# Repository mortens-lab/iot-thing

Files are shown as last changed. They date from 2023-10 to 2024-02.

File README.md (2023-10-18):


# iot-thing
Universal iot device based on an ESP32 WROOM module

KiCad 7.0 files for device

<a href="https://www.pcbway.com/project/shareproject/iot_thing_universal_iot_development_board_fe54c4ad.html">PCB from PCBWay</a>

IMAGE ALT TEXT (http://www.youtube.com/watch?v=b-7bMl6fJio "Video Title")

Link to YouTube video : (https://youtu.be/b-7bMl6fJio)

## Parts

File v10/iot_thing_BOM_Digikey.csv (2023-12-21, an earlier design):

Reference | Value | Footprint | Digikey | Qty
C1, C3, C7, C9, C10, C13, C14 | 100n | Capacitor_SMD:C_0402_1005Metric_Pad0.74x0.62mm_HandSolder | 490-10700-1-ND | 7
C2, C4, C6, C8, C11, C12 | 22u | Capacitor_SMD:C_0805_2012Metric | 1276-2910-1-ND | 6
C5 | 4u7 | Capacitor_SMD:C_0805_2012Metric | 1276-6464-1-ND | 1
C15 | 1000u/25V | Capacitor_THT:CP_Radial_D10.0mm_P5.00mm | 732-8835-1-ND | 1
C16 | 4u7 | Capacitor_SMD:C_0805_2012Metric_Pad1.18x1.45mm_HandSolder | 1276-6464-1-ND | 1
D1 | LED_RGBA | LED_SMD:LED_RGB_Wuerth-PLCC4_3.2x2.8mm_150141M173100 | 732-4998-1-ND | 1
D2 | LL4148 | Diode_SMD:D_MiniMELF | 4878-LL4148CT-ND | 1
D3 | YELLOW | LED_SMD:LED_0603_1608Metric | 732-4981-1-ND | 1
D4 | GREEN | LED_SMD:LED_0603_1608Metric | 732-4980-1-ND | 1
F1 | Polyfuse 1A | Fuse:Fuse_1206_3216Metric | F3371CT-ND | 1
F3 | Fuse | 00_morten_Library:FUSE_696105003002 | 732-11373-ND | 1
FB1 | BLM21PG221 | Inductor_SMD:L_0805_2012Metric_Pad1.05x1.20mm_HandSolder | 490-1054-1-ND | 1
H1-H4 | Hole_Pad | MountingHole:MountingHole_3.2mm_M3_Pad_Via | N/A | 4
J1 | Conn_01x04 | Connector_JST:JST_SH_SM04B-SRSS-TB_1x04-1MP_P1.00mm_Horizontal | 455-SM04B-SRSS-TBCT-ND | 1
J2 | USB_C_Receptacle_USB2.0 | Connector_USB:USB_C_Receptacle_HRO_TYPE-C-31-M-12 | LCSC : Korean Hroparts Elec TYPE-C-31-M-12 | 1
J3 | Screw_Terminal_01x03 | TerminalBlock_Phoenix:TerminalBlock_Phoenix_MKDS-3-3-5.08_1x03_P5.08mm_Horizontal | 732-10996-ND | 1
J4 | Screw_Terminal_01x02 | TerminalBlock_Phoenix:TerminalBlock_Phoenix_MKDS-1,5-2-5.08_1x02_P5.08mm_Horizontal | 732-691253510002-ND | 1
J5 | Screw_Terminal_01x08 | TerminalBlock_Phoenix:TerminalBlock_Phoenix_MKDS-1,5-8-5.08_1x08_P5.08mm_Horizontal | 732-691244510008-ND | 1
J6 | Conn_02x05_Odd_Even | Connector_PinHeader_2.54mm:PinHeader_2x05_P2.54mm_Vertical | Standard Pins 2x5 0.254 | 1
K1 | RT314A05 | Relay_THT:Relay_SPDT_Schrack-RT1-16A-FormC_RM5mm | PB1695-ND | 1
Q2 | UMH3N | Package_TO_SOT_SMD:SOT-363_SC-70-6 | UMH3NFHATNCT-ND | 1
Q3 | BC817 | Package_TO_SOT_SMD:SOT-23 | BC817-40-TPMSCT-ND | 1
R1, R6, R12, R14 | 10K | Resistor_SMD:R_0402_1005Metric_Pad0.72x0.64mm_HandSolder | 311-10.0KLRCT-ND | 4
R2, R3 | 5K1 | Resistor_SMD:R_0402_1005Metric_Pad0.72x0.64mm_HandSolder | 311-5.10KLRCT-ND | 2
R4, R5 | 4K7 | Resistor_SMD:R_0402_1005Metric_Pad0.72x0.64mm_HandSolder | 311-4.7KLRCT-ND | 2
R7, R8 | 22R | Resistor_SMD:R_0402_1005Metric_Pad0.72x0.64mm_HandSolder | 311-22.0LRCT-ND | 2
R9-R11, R13, R15, R16 | 1K | Resistor_SMD:R_0402_1005Metric_Pad0.72x0.64mm_HandSolder | 311-1.00KLRCT-ND | 6
R17-R20 | 47R | Resistor_SMD:R_0402_1005Metric_Pad0.72x0.64mm_HandSolder | 311-47.0LRCT-ND | 4
SW1 | SW_SPST | Button_Switch_SMD:SW_Push_1P1T_NO_6x6mm_H9.5mm | 679-2380-1-ND | 1
U1 | ESP32-WROOM-32D | RF_Module:ESP32-WROOM-32D | 1965-ESP32-WROOM-32E-N4CT-ND | 1
U2 | USBLC6-2P6 | Package_TO_SOT_SMD:SOT-666 | 497-5026-1-ND | 1
U3 | Si7021-A20 | Package_DFN_QFN:DFN-6-1EP_3x3mm_P1mm_EP1.5x2.4mm | 336-4380-1-ND | 1
U4 | CP2104 | Package_DFN_QFN:QFN-24-1EP_4x4mm_P0.5mm_EP2.6x2.6mm | 336-4146-1-ND | 1
U5 | TLV1117LV-33 | Package_TO_SOT_SMD:SOT-223-3_TabPin2 | 296-28778-1-ND | 1
U6 | 74AHCT245 | Package_DIP:DIP-20_W7.62mm | 296-1476-5-ND | 1

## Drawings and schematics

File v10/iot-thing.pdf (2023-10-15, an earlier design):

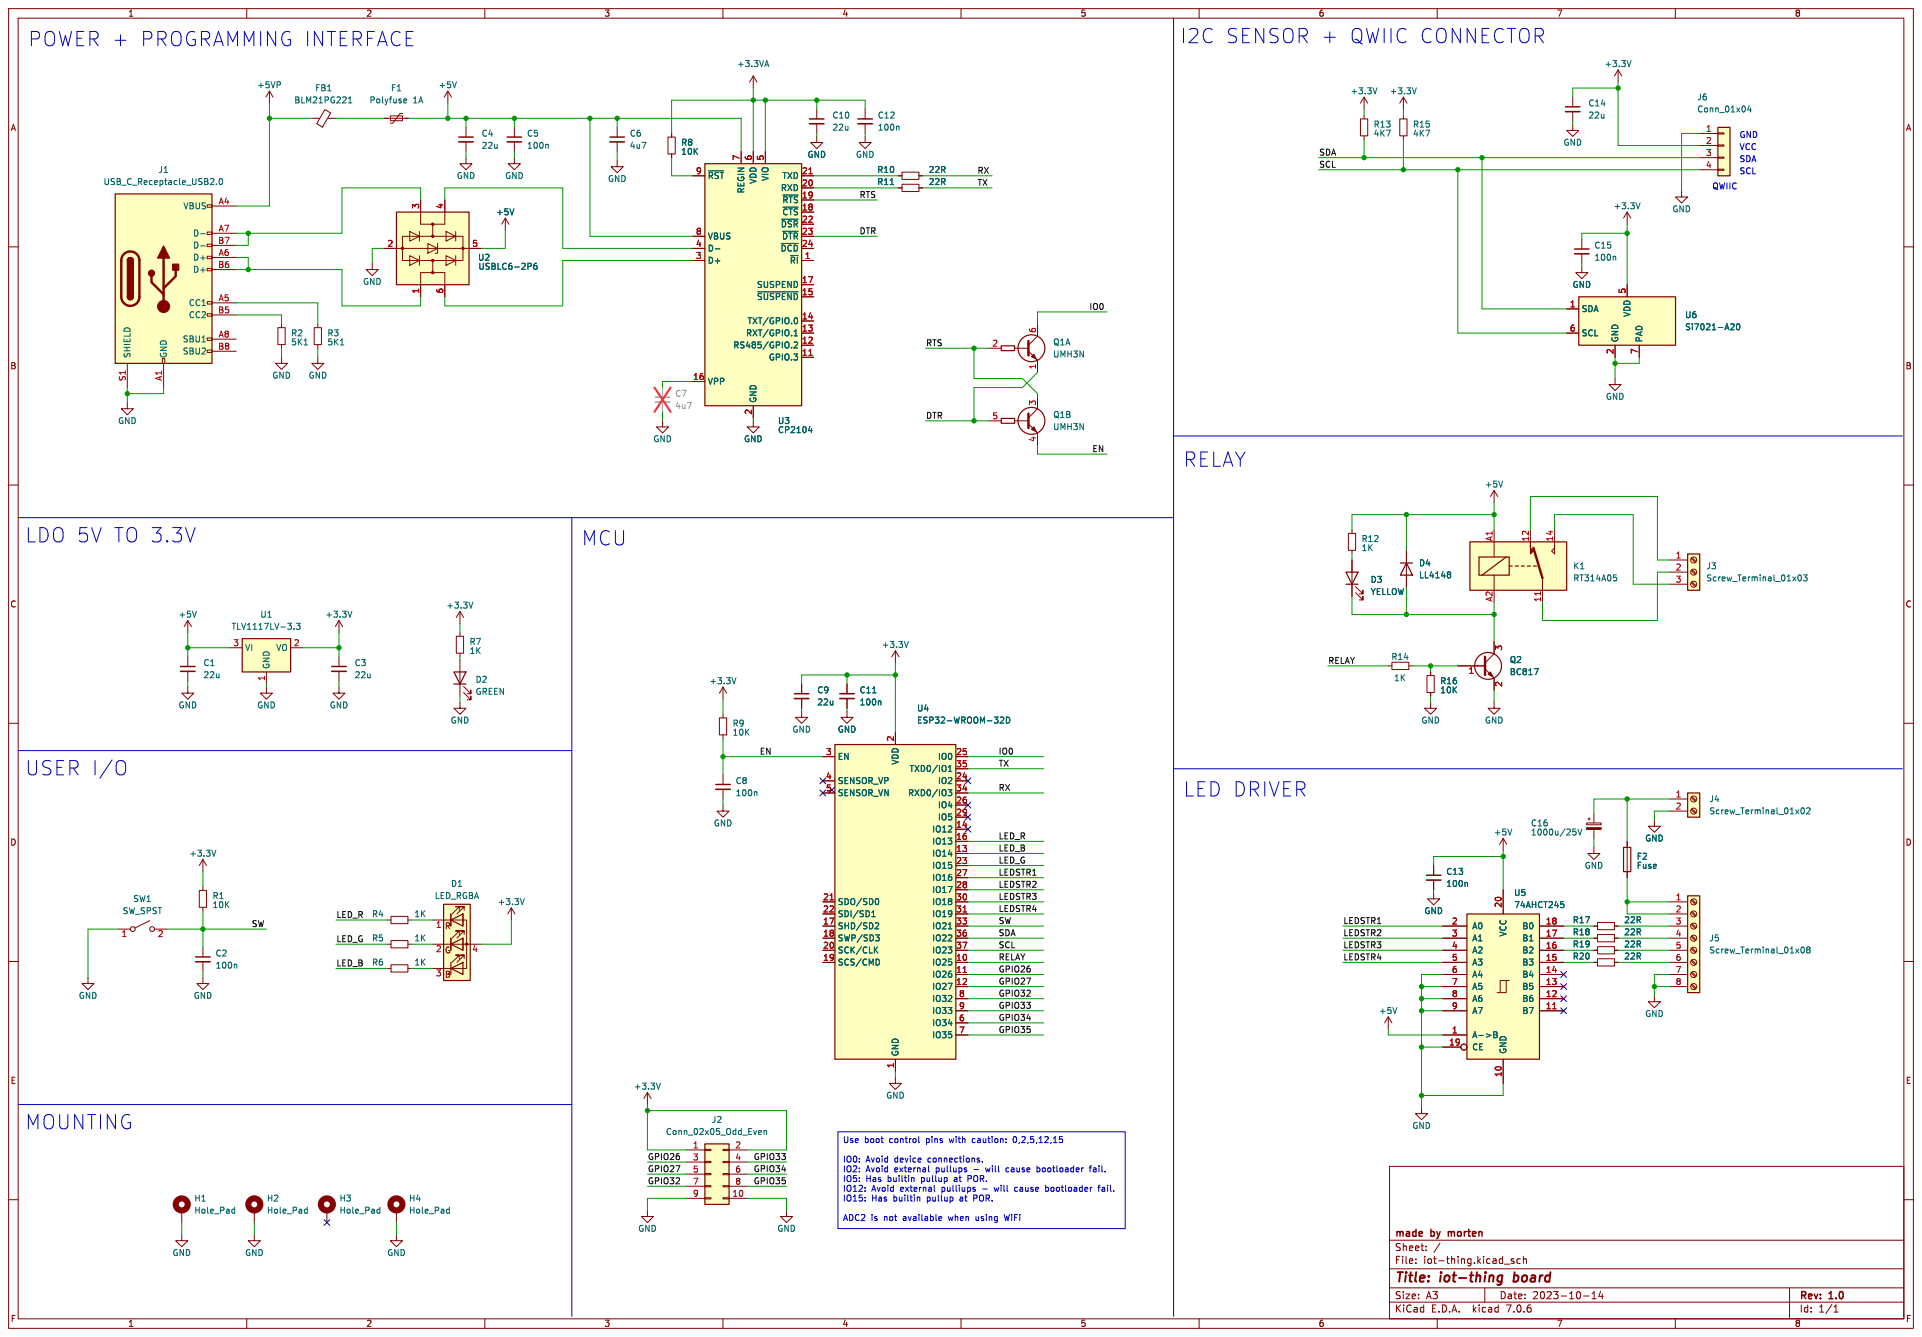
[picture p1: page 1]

2 RXD 20 TXD 21 ~{DSR} 22 ~{DTR} 23 ~{DCD} 24 D+ 3 D- 4 VIO

7 U6Si7021-A20 GND GND GND GND A1 VBUS A4 CC1 A5 D+ A6 D- A7 SBU1 A8 CC2 B5 D+ B6 D- B7 SBU2 B8 SHIELD S1

2 SCK/CLK 20 SDO/SD0 21 SDI/SD1 22

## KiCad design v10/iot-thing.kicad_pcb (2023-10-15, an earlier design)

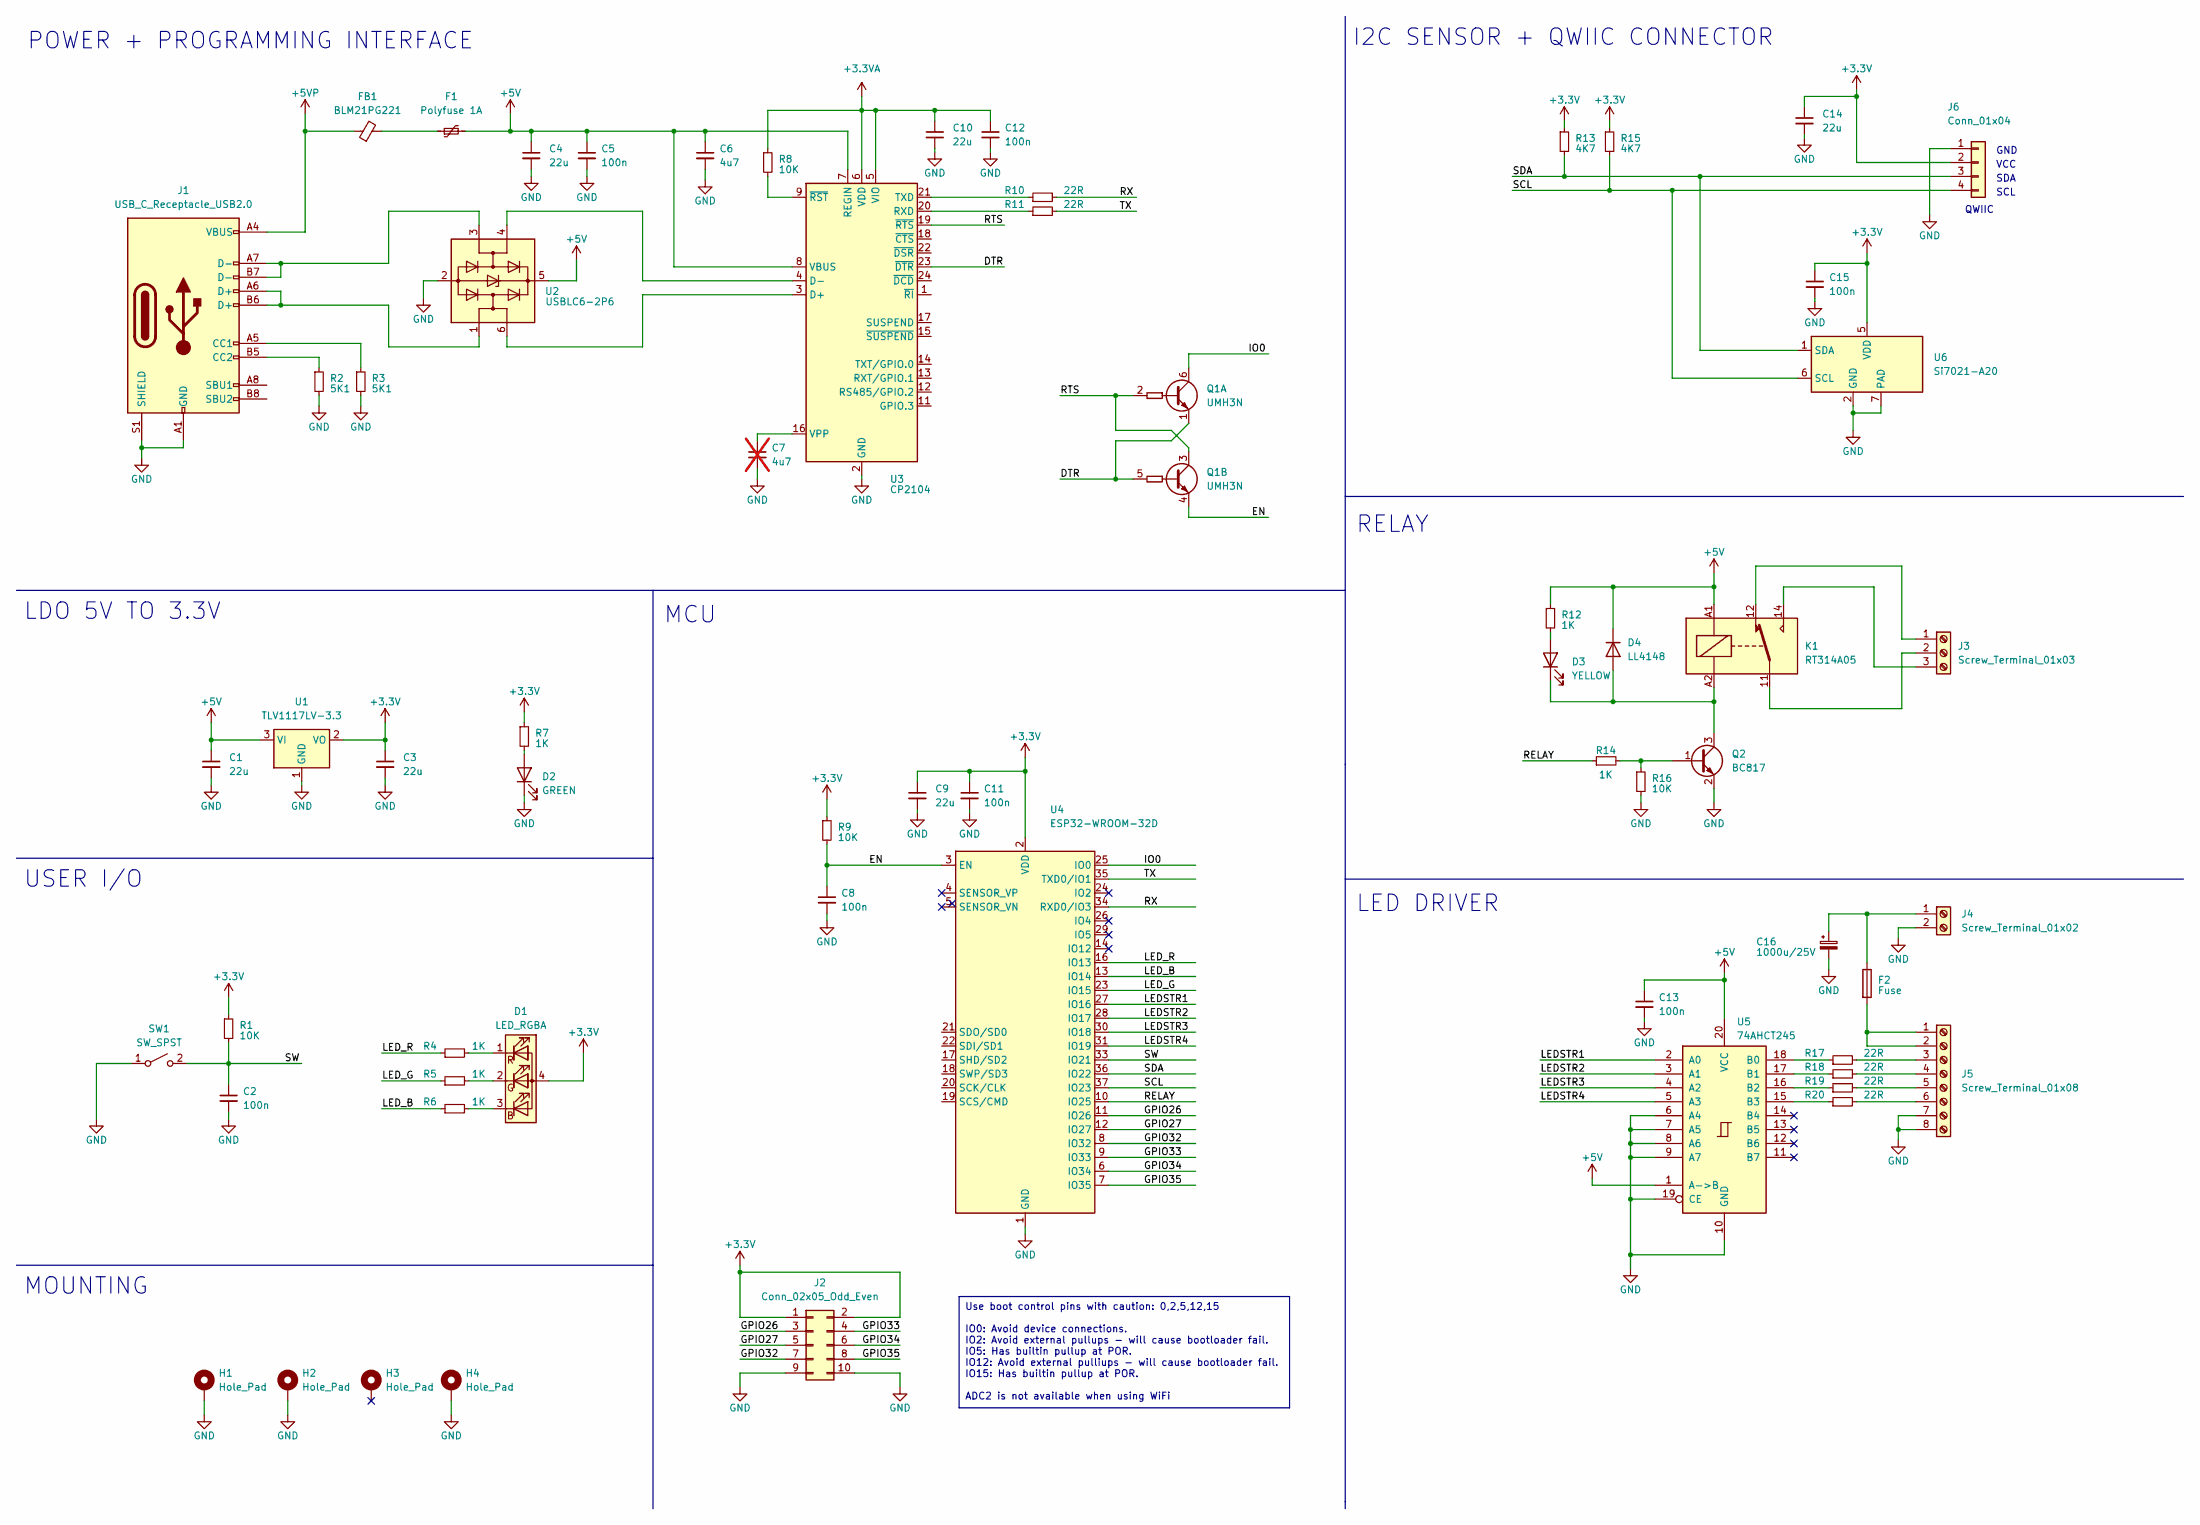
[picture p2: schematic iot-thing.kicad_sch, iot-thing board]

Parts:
C1, C3, C4, C9, C10, C14: 22u; C_0805_2012Metric_Pad1.18x1.45mm_HandSolder
C2, C5, C8, C11, C12, C13, C15: 100n; C_0402_1005Metric_Pad0.74x0.62mm_HandSolder
C6: 4u7; C_0805_2012Metric_Pad1.18x1.45mm_HandSolder
C7: 4u7; C_0805_2012Metric_Pad1.18x1.45mm_HandSolder; not fitted
C16: 1000u/25V; CP_Radial_D10.0mm_P5.00mm
D1: LED_RGBA; LED_RGB_Wuerth-PLCC4_3.2x2.8mm_150141M173100
D2: GREEN; LED_0603_1608Metric_Pad1.05x0.95mm_HandSolder
D3: YELLOW; LED_0603_1608Metric_Pad1.05x0.95mm_HandSolder
D4: LL4148; D_MiniMELF
F1: Polyfuse 1A; Fuse_1206_3216Metric_Pad1.42x1.75mm_HandSolder
F2: Fuse; FUSE_696105003002
FB1: BLM21PG221; L_0603_1608Metric_Pad1.05x0.95mm_HandSolder
H1, H2, H4: Hole_Pad; MountingHole_3.2mm_M3_Pad_Via
H3: Hole_Pad; MountingHole_3.2mm_M3_DIN965
J1: USB_C_Receptacle_USB2.0; USB_C_Receptacle_HRO_TYPE-C-31-M-12
J2: Conn_02x05_Odd_Even; PinHeader_2x05_P2.54mm_Vertical
J3: Screw_Terminal_01x03; TerminalBlock_Phoenix_MKDS-3-3-5.08_1x03_P5.08mm_Horizontal
J4: Screw_Terminal_01x02; TerminalBlock_Phoenix_MKDS-1,5-2-5.08_1x02_P5.08mm_Horizont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
J5: Screw_Terminal_01x08; TerminalBlock_Phoenix_MKDS-1,5-8_1x08_P5.00mm_Horizontal
J6: Conn_01x04; JST_SH_SM04B-SRSS-TB_1x04-1MP_P1.00mm_Horizontal
K1: RT314A05; Relay_SPDT_Schrack-RT1-16A-FormC_RM5mm
Q1: UMH3N; SOT-363_SC-70-6
Q2: BC817; SOT-23
R1, R8, R9, R16: 10K; R_0402_1005Metric_Pad0.72x0.64mm_HandSolder
R2, R3: 5K1; R_0402_1005Metric_Pad0.72x0.64mm_HandSolder
R4, R5, R6, R7, R12, R14: 1K; R_0402_1005Metric_Pad0.72x0.64mm_HandSolder
R10, R11, R17, R18, R19, R20: 22R; R_0402_1005Metric_Pad0.72x0.64mm_HandSolder
R13, R15: 4K7; R_0402_1005Metric_Pad0.72x0.64mm_HandSolder
SW1: SW_SPST; SW_Push_1P1T_NO_6x6mm_H9.5mm
U1: TLV1117LV-3.3; SOT-223-3_TabPin2
U2: USBLC6-2P6; SOT-666
U3: CP2104; QFN-24-1EP_4x4mm_P0.5mm_EP2.6x2.6mm
U4: ESP32-WROOM-32D
U5: 74AHCT245; DIP-20_W7.62mm
U6: Si7021-A20; DFN-6-1EP_3x3mm_P1mm_EP1.5x2.4mm

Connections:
+3.3V: C3.1, C9.1, C11.1, C14.1, C15.1, D1.4 (A), J2.1, J2.2, J6.2, R1.1, R7.1, R9.1, R13.1, R15.1, U1.2 (VO), U4.2 (VDD), U6.5 (VDD)
+3.3VA: C10.1, C12.1, R8.1, U3.5 (VIO), U3.6 (VDD)
+5V: C1.1, C4.1, C5.1, C6.1, C13.1, D4.1 (K), F1.2, K1.A1, R12.1, U1.3 (VI), U2.5 (VBUS), U3.7 (REGIN), U3.8 (VBUS), U5.1 (A->B), U5.20 (VCC)
+5VP: FB1.1, J1.A4 (VBUS), J1.A9 (VBUS), J1.B4 (VBUS), J1.B9 (VBUS)
/DTR: Q1.1 (E1), Q1.5 (B2), U3.23 (~DTR)
/EN: C8.1, Q1.4 (E2), R9.2, U4.3 (EN)
/GPIO26: J2.3, U4.11 (IO26)
/GPIO27: J2.5, U4.12 (IO27)
/GPIO32: J2.7, U4.8 (IO32)
/GPIO33: J2.4, U4.9 (IO33)
/GPIO34: J2.6, U4.6 (IO34)
/GPIO35: J2.8, U4.7 (IO35)
/IO0: Q1.6 (C1), U4.25 (IO0)
/LEDSTR1: U4.27 (IO16), U5.2 (A0)
/LEDSTR2: U4.28 (IO17), U5.3 (A1)
/LEDSTR3: U4.30 (IO18), U5.4 (A2)
/LEDSTR4: U4.31 (IO19), U5.5 (A3)
/LED_B: R6.1, U4.13 (IO14)
/LED_G: R5.1, U4.23 (IO15)
/LED_R: R4.1, U4.16 (IO13)
/RELAY: R14.1, U4.10 (IO25)
/RTS: Q1.2 (B1), Q1.3 (C2), U3.19 (~RTS)
/RX: R10.2, U4.34 (RXD0/IO3)
/SCL: J6.4, R15.2, U4.37 (IO23), U6.6 (SCL)
/SDA: J6.3, R13.2, U4.36 (IO22), U6.1 (SDA)
/SW: C2.1, R1.2, SW1.2 (B), U4.33 (IO21)
/TX: R11.2, U4.35 (TXD0/IO1)
GND: C1.2, C2.2, C3.2, C4.2, C5.2, C6.2, C7.2, C8.2, C9.2, C10.2, C11.2, C12.2, C13.2, C14.2, C15.2, C16.2, D2.1 (K), H1.1, H2.1, H4.1, J1.A1 (GND), J1.A12 (GND), J1.B1 (GND), J1.B12 (GND), J1.S1 (SHIELD), J2.9, J2.10, J4.2, J5.7, J5.8, J6.1, Q2.2 (E), R2.2, R3.2, R16.2, SW1.1 (A), U1.1 (GND), U2.2 (GND), U3.2 (GND), U3.25 (GND), U4.1 (GND), U4.15 (GND), U4.38 (GND), U4.39 (GND), U5.6 (A4), U5.7 (A5), U5.8 (A6), U5.9 (A7), U5.10 (GND), U5.19 (CE), U6.2 (GND), U6.7 (PAD)
unnamed: D1.3 (BK), R6.2
unnamed: D1.2 (GK), R5.2
unnamed: D1.1 (RK), R4.2
unnamed: D2.2 (A), R7.2
unnamed: D3.2 (A), R12.2
unnamed: D3.1 (K), D4.2 (A), K1.A2, Q2.3 (C)
unnamed: F1.1, FB1.2
unnamed: J1.A5 (CC1), R3.1
unnamed: J1.B5 (CC2), R2.1
unnamed: J1.A6 (D+), J1.B6 (D+), U2.1 (I/O1)
unnamed: J1.A7 (D-), J1.B7 (D-), U2.3 (I/O2)
unnamed: J3.1, K1.12
unnamed: J3.2, K1.11
unnamed: J3.3, K1.14
unnamed: C16.1, F2.1, J4.1
unnamed: F2.2, J5.1, J5.2
unnamed: J5.3, R17.2
unnamed: J5.4, R18.2
unnamed: J5.5, R19.2
unnamed: J5.6, R20.2
unnamed: Q2.1 (B), R14.2, R16.1
unnamed: U2.6 (I/O1), U3.3 (D+)
unnamed: U2.4 (I/O2), U3.4 (D-)
unnamed: R11.1, U3.20 (RXD)
unnamed: R10.1, U3.21 (TXD)
unnamed: C7.1, U3.16 (VPP)
unnamed: R8.2, U3.9 (~RST)
unnamed: R17.1, U5.18 (B0)
unnamed: R18.1, U5.17 (B1)
unnamed: R19.1, U5.16 (B2)
unnamed: R20.1, U5.15 (B3)

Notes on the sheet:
Use boot control pins with caution: 0,2,5,12,15 IO0: Avoid device connections. IO2: Avoid external pullups - will cause bootloader fail. IO5: Has builtin pullup at POR. IO12: Avoid external pulliups - will cause bootloader fail. IO15: Has builtin pullup at POR. ADC2 is not available when using WiFi
LDO 5V TO 3.3V
MOUNTING
GND
SCL
SDA
I2C SENSOR + QWIIC CONNECTOR
USER I/O
RELAY
MCU
QWIIC
LED DRIVER
POWER + PROGRAMMING INTERFACE
VCC

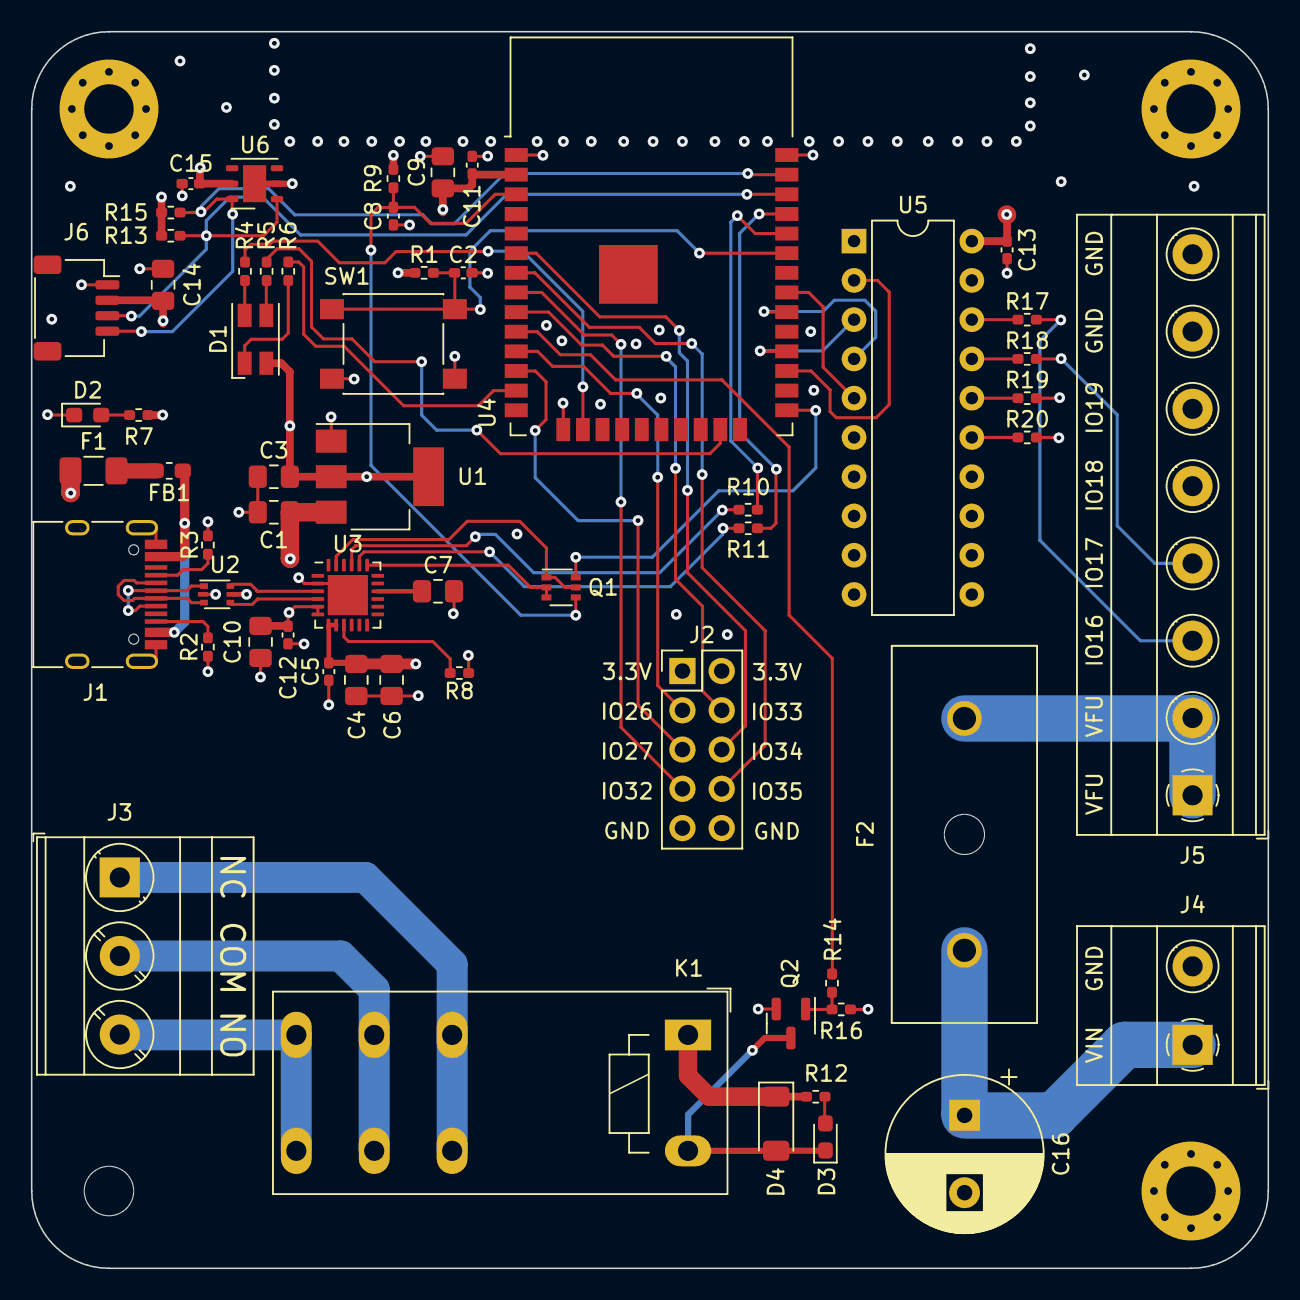
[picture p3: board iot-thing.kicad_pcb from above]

Board: 4 copper layers, 80.0 x 80.0 mm, 63 parts (0 on the bottom side), 59 nets.

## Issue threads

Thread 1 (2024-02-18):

4 channel replays

ajay01994, 2024-02-18:
Hi ,

Thanks you so much for your tutorial its very helpful to us ,   in your existing board i need to add 4 relays for motor controls like this project -https://github.com/Lmanangka/esp32-4-channel-relays , could you help me on how to do that any schematic diagram will help .

Thanks in advance !

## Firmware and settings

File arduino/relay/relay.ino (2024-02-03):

#define SDA     22 
#define SCL     23 
#define LED_R   15
#define LED_G   14
#define LED_B   13
#define RELAY   25
#define LEDSTR1 16
#define LEDSTR2 17
#define LEDSTR3 18
#define LEDSTR4 19
#define SW      21
#define GPIO26  26
#define GPIO27  27
#define GPIO32  32
#define GPIO33  33
#define GPIO34  34
#define GPIO35  35


void setup() 
{
  pinMode(RELAY, OUTPUT);
  pinMode(SW, INPUT);
  pinMode(LED_R, OUTPUT);
  pinMode(LED_G, OUTPUT);
  pinMode(LED_B, OUTPUT);
  digitalWrite(RELAY, LOW);  
  digitalWrite(LED_R, HIGH);  
  digitalWrite(LED_G, HIGH);  
  digitalWrite(LED_B, HIGH);  
  delay(1000);
  digitalWrite(LED_R, LOW);    // RED
  delay(1000);
  digitalWrite(LED_R, HIGH);  
  delay(300);
  digitalWrite(LED_G, LOW);    // GREEN
  delay(1000);
  digitalWrite(LED_G, HIGH);  
  delay(300);
  digitalWrite(LED_B, LOW);    // BLUE
  delay(1000);
  digitalWrite(LED_B, HIGH);  
  delay(300);
}


void loop() 
{
  if (digitalRead(SW)==1)
  {
    digitalWrite(RELAY, LOW);  
    digitalWrite(LED_R, HIGH);  
  }
  else
  {
    digitalWrite(RELAY, HIGH);  
    digitalWrite(LED_R, LOW);  
  }
}

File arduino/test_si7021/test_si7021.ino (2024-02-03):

/* Si7021 sensor reading without library
 *  Datasheet:      https://www.silabs.com/documents/public/data-sheets/Si7021-A20.pdf
 */

 /******************************I2C COMMAND TABLE*****************************
  * Measure Relative Humidity, Hold Master Mode         0xE5
  * Measure Relative Humidity, No Hold Master Mode      0xF5 
  * Measure Temperature, Hold Master Mode               0xE3
  * Measure Temperature, No Hold Master Mode            0xF3
  * Read Temperature Value from Previous RH Measurement 0xE0
  * Reset                                               0xFE  
  * Write RH/T User Register 1                          0xE6
  * Read RH/T User Register 1                           0xE7
  * Write Heater Control Register                       0x51
  * Read Heater Control Register                        0x11
  * Read Electronic ID 1st Byte                         0xFA 0x0F
  * Read Electronic ID 2nd Byte                         0xFC 0xC9
  * Read Firmware Revision                              0x84 0xB8
  * 
  * source datasheet
  */

// This library allows you to communicate with I2C / TWI devices.
#include <Wire.h>
 
// SI7021 I2C address is 0x40(64)
#define si7021Addr 0x40

// data pins for i2c, can be anything for ESP8266 
// for Arduino:
// Board              I2C / TWI pins
// Uno, Ethernet      A4 (SDA),   A5 (SCL)
// Mega2560           20 (SDA),   21 (SCL)
// Leonardo            2 (SDA),    3 (SCL)
// Due                20 (SDA),   21 (SCL)

#define SDA     22 
#define SCL     23 
#define LED_R   13
#define LED_G   14
#define LED_B   15
#define RELAY   25
#define LEDSTR1 16
#define LEDSTR2 17
#define LEDSTR3 18
#define LEDSTR4 19
#define SW      21
#define GPIO26  26
#define GPIO27  27
#define GPIO32  32
#define GPIO33  33
#define GPIO34  34
#define GPIO35  35

// function for reading values into a array of unsigned int data[2] 
// from the Si7021 with a specific i2c address si7021Addr=0x40
// with one of the commands listed above. Function body at the end of this sketch
void getSiData(unsigned int *_ret_data, byte _i2c_command);
 
void setup()
{
  // Initiate the Wire library and join the I2C bus
  Wire.begin(SDA,SCL);
  
  Serial.begin(115200);

  //reset sensor by sending 0xFE command to the Si7021 address
  Wire.beginTransmission(si7021Addr);
  Wire.write(0xFE); // Write reset command
  Wire.endTransmission();
  delay(15); // Default = 15ms

  
}
 
void loop()
{
  //sensor returns 2 bytes via I2C. It will be converted to temperature or humidity later
  unsigned int data[2];
 
  //Send humidity measurement command and get response into the array 'data'
  getSiData(data, 0xE5);
 
  // Convert the data
  float humidity  = ((data[0] * 256.0) + data[1]);
  humidity = ((125 * humidity) / 65536.0) - 6;
 
  // Send temperature measurement command
  getSiData(data, 0xE3);
  
  /* re-use temperature already measured by humidity measurement some milliseconds before command -> E0
    *getSiData(data, 0xE0); 
    *
    *However, does not report valid results
    *
    *Datasheet: 
    *Each time a relative humidity measurement is made a temperature measurement is also made for the purposes of
    *temperature  compensation  of  the  relative  humidity  measurement.  If  the  temperature  value  is  required,  
    *it  can  be read  using  command  0xE0;  this  avoids  having  to  perform  a  second  temperature  measurement.  
    *The  measure temperature  commands 0xE3  and  0xF3  will  perform  a  temperature measurement  and  return  the  
    *measurement value, command 0xE0 does not perform a measurement but returns the temperature value measured during the
    *relative humidity measurement. 
   
  */ 
  
  // Convert the data
  float temp  = ((data[0] * 256.0) + data[1]);
  float celsTemp = ((175.72 * temp) / 65536.0) - 46.85;
  float fahrTemp = celsTemp * 1.8 + 32;
 
  // Output data to serial monitor
  Serial.print("Humidity : ");
  Serial.print(humidity);
  Serial.println(" % RH");
  Serial.print("Celsius : ");
  Serial.print(celsTemp);
  Serial.println(" C");
  delay(10000);
}



void getSiData(unsigned int *_ret_data, byte _i2c_command)
{

  // start i2c communication 
  Wire.beginTransmission(si7021Addr);
  //send i2c command to sensor
  Wire.write(_i2c_command);
  // we are done with our transmission...close i2c communication
  Wire.endTransmission();
  delay(85);
 
  // Request 2 bytes of data
  Wire.requestFrom(si7021Addr, 2);
  // Read 2 bytes of data and save it to _ret_data which points to 'data[2]'
  if(Wire.available() == 2)
  {
    _ret_data[0] = Wire.read();
    _ret_data[1] = Wire.read();
  }
}
